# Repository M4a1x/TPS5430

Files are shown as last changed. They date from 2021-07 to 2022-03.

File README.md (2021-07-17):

# TPS5430

This is a small DC-DC Buck converter board based on the TPS5430 from TI specifically intended to be ordered from [JLCPCB](jlcpcb.com/) with few "extended parts". This was a practice project for me, so please feel free to point out any [issues](https://github.com/M4a1x/TPS5430/issues).

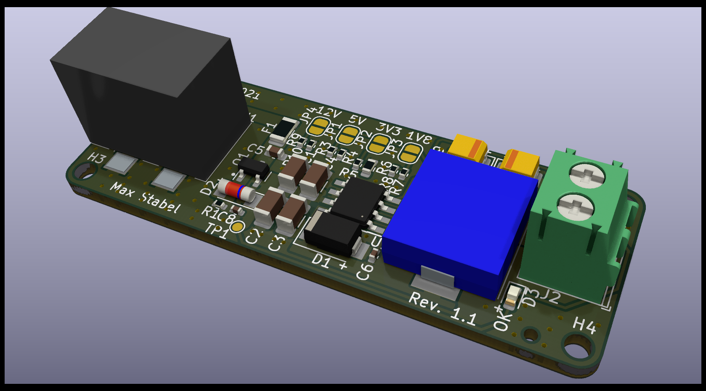
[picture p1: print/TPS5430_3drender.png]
Raytrace 3D rendered image of the TPS5430 board TPS5430


## Features

* V<sub>in</sub> = 5.5V..36V
* V<sub>in<sub>min</sub></sub> = 1.15 * V<sub>out</sub> (see Datasheet Section 8.2.1.2.8.1)
* V<sub>in<sub>max</sub></sub> = 8.33 * (V<sub>out</sub> + 0.5) (see Datasheet Section 8.2.1.2.8.1)
* V<sub>out</sub> = 1.8V/3.3V/5V/12V (choose via solder bridge)
* Reverse polarity protection with AO3401A p-MOSFET
* 3A (hold)/6A (trip) polyfuse input protection
* The board can be powered with a 2.1mm/5.5mm "standard" Arduino compatible barrel jack connector.
* Status LED

## Schematic

The design was done in [KiCAD 6 nightly (aka 5.99)](https://www.kicad.org/) and follows the [TPS5430 datasheet (Section 8.2.1)](https://www.ti.com/lit/ds/symlink/tps5430.pdf) reasonably close in the schmatic as well as the layout (Section 10.2).

Deviations are:

* 2x 100uF tantalum capacitors instead of 1x 220uF, since those are basic parts at JLCPCB
* As suggested a 10uF output bypass capacitor is added
* 4x 10uF input capacitors instead of only 1x
* Multiple output voltage options through increased Inductor (47uH instead of 15uH) and solder jumpers. All outputs should work with the full 3A

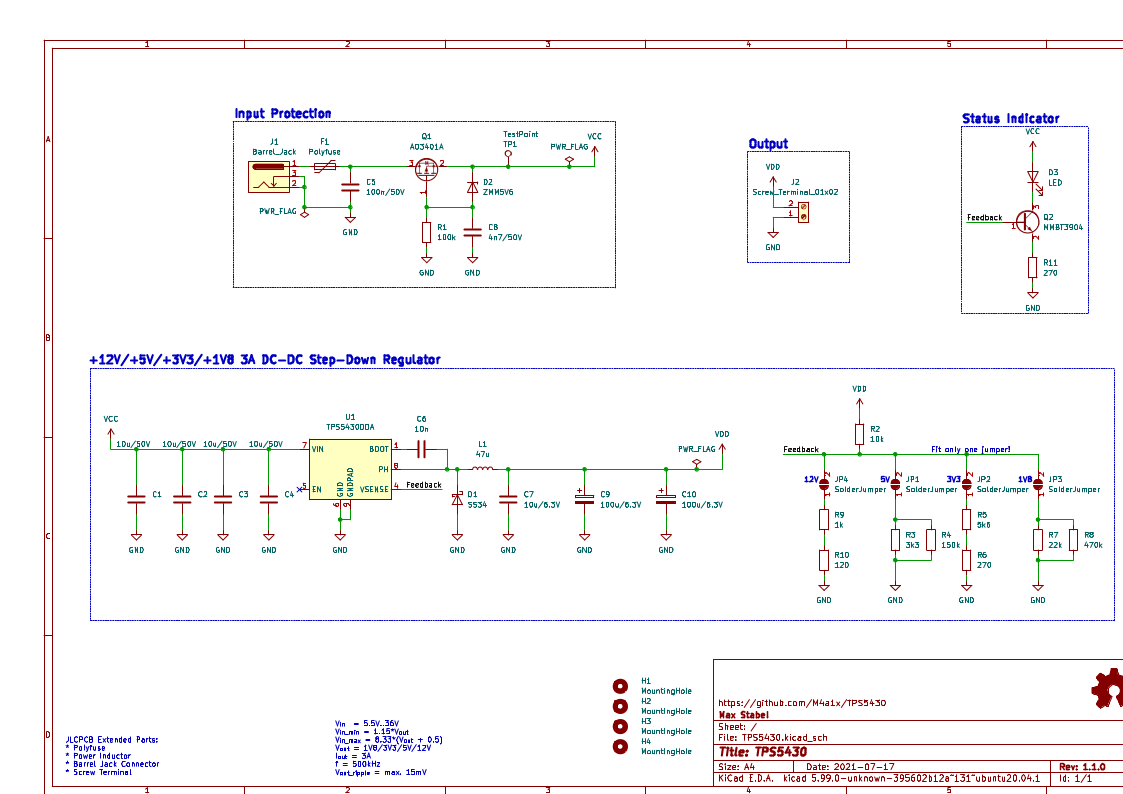
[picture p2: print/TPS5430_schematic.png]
Full schematic of the TPS5430 board Schematic


## License

Licensed under CERN-OHL-S v2 or any later version. See `LICENSE` for more information.

## Contact

Max Stabel - [https://max.stabel.family/](https://max.stabel.family)

Project Link: [https://github.com/M4a1x/TPS5430](https://github.com/M4a1x/TPS5430)

## Acknowledgements

* [Philip Salamony](https://philsal.co.uk/) and his [BananaSchplit Project](https://github.com/pms67/BananaSchplit) and [Video](https://www.youtube.com/watch?v=qXWYXxDokv4)
* [ugurozkan52/TPS5430_Power_Module](https://github.com/ugurozkan52/TPS5430_Power_Module) which inspired me to add the output voltage jumpers

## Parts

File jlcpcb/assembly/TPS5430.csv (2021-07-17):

Comment | Designator | Footprint | LCSC
10u/50V | C1,C2,C3,C4 | Capacitor_SMD:C_1206_3216Metric | C13585
100n/50V | C5 | Capacitor_SMD:C_0603_1608Metric | C14663
10n | C6 | Capacitor_SMD:C_0402_1005Metric | C15195
10u/6.3V | C7 | Capacitor_SMD:C_0402_1005Metric | C15525
4n7/50V | C8 | Capacitor_SMD:C_0402_1005Metric | C1538
100u/6.3V | C9,C10 | Capacitor_Tantalum_SMD:CP_EIA-3528-21_Kemet-B | C16133
SS34 | D1 | Diode_SMD:D_SMA | C8678
ZMM5V6 | D2 | Diode_SMD:D_MiniMELF | C8062
LED | D3 | LED_SMD:LED_0603_1608Metric | C72043
Polyfuse | F1 | Fuse:Fuse_1206_3216Metric | C207041
MountingHole | H1,H2,H3,H4 | MountingHole:MountingHole_2.2mm_M2_ISO7380
Barrel_Jack | J1 | tps5430:DC-005-5A-2.0-SMT | C319134
Screw_Terminal_01x02 | J2 | TerminalBlock_Phoenix:TerminalBlock_Phoenix_PT-1,5-2-3.5-H_1x02_P3.50mm_Horizontal | C784940
SolderJumper | JP1,JP2,JP3,JP4 | Jumper:SolderJumper-2_P1.3mm_Open_RoundedPad1.0x1.5mm
47u | L1 | tps5430:L_Sunlord_MWSA1004S_10x11.5x4mm | C408491
Logo_Open_Hardware_Small | LOGO1 | Symbol:OSHW-Logo_11.4x12mm_Copper
AO3401A | Q1 | Package_TO_SOT_SMD:SOT-23 | C15127
MMBT3904 | Q2 | Package_TO_SOT_SMD:SOT-23 | C20526
100k | R1 | Resistor_SMD:R_0402_1005Metric | C25741
120 | R10 | Resistor_SMD:R_0402_1005Metric | C25079
10k | R2 | Resistor_SMD:R_0402_1005Metric | C25744
3k3 | R3 | Resistor_SMD:R_0402_1005Metric | C25890
150k | R4 | Resistor_SMD:R_0402_1005Metric | C25755
5k6 | R5 | Resistor_SMD:R_0402_1005Metric | C25908
270 | R6,R11 | Resistor_SMD:R_0603_1608Metric | C22966
22k | R7 | Resistor_SMD:R_0402_1005Metric | C25768
470k | R8 | Resistor_SMD:R_0402_1005Metric | C25790
1k | R9 | Resistor_SMD:R_0402_1005Metric | C11702
TestPoint | TP1 | TestPoint:TestPoint_Pad_D1.0mm
TPS5430DDA | U1 | Package_SO:TI_SO-PowerPAD-8_ThermalVias | C9864

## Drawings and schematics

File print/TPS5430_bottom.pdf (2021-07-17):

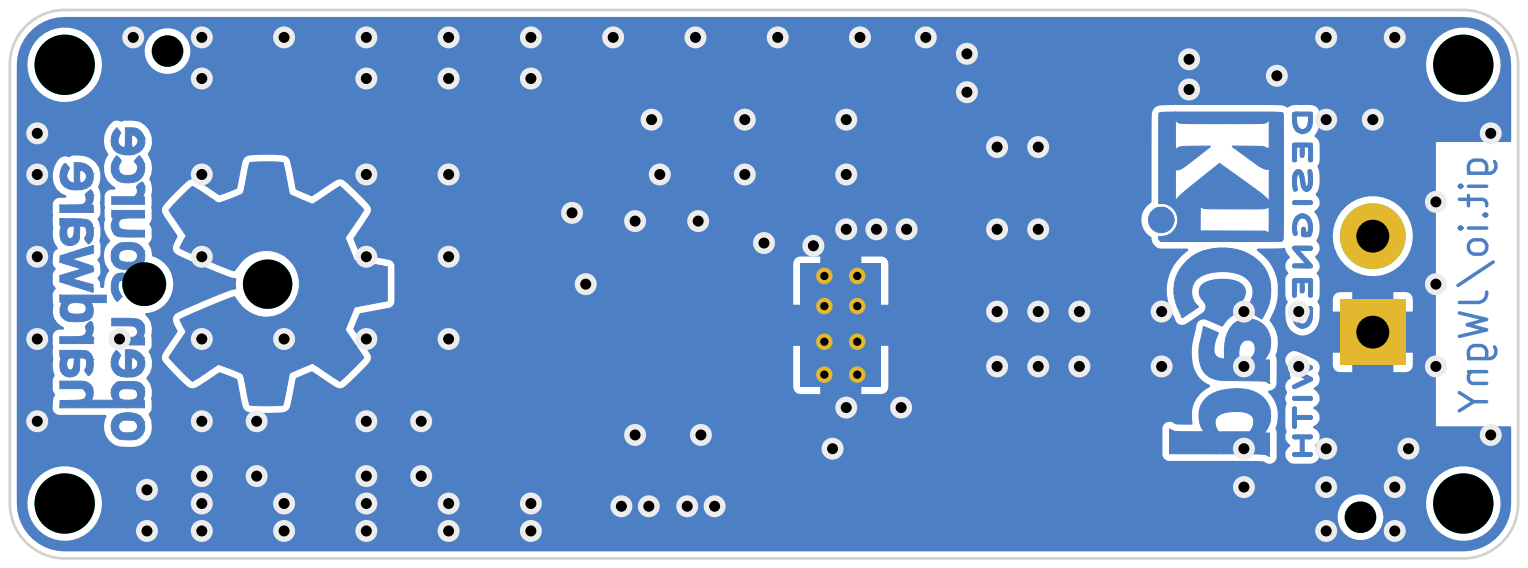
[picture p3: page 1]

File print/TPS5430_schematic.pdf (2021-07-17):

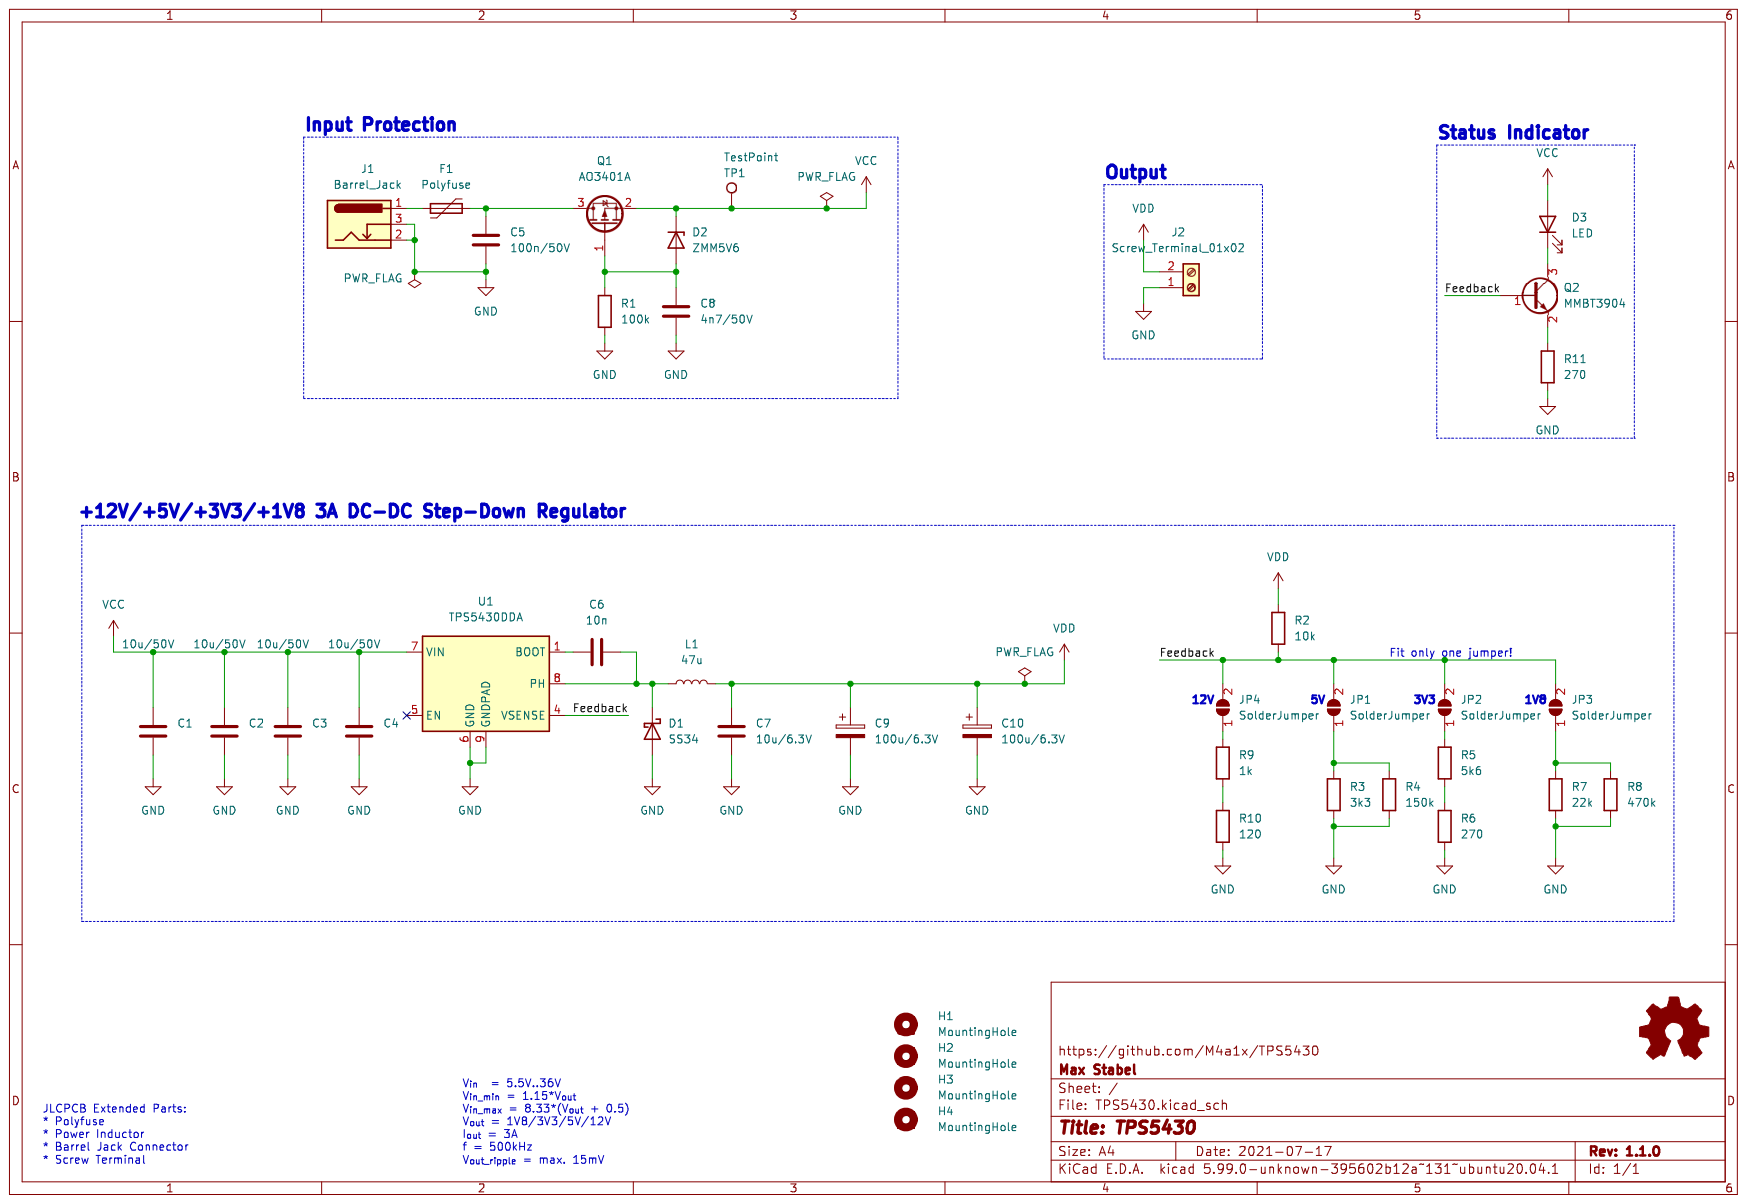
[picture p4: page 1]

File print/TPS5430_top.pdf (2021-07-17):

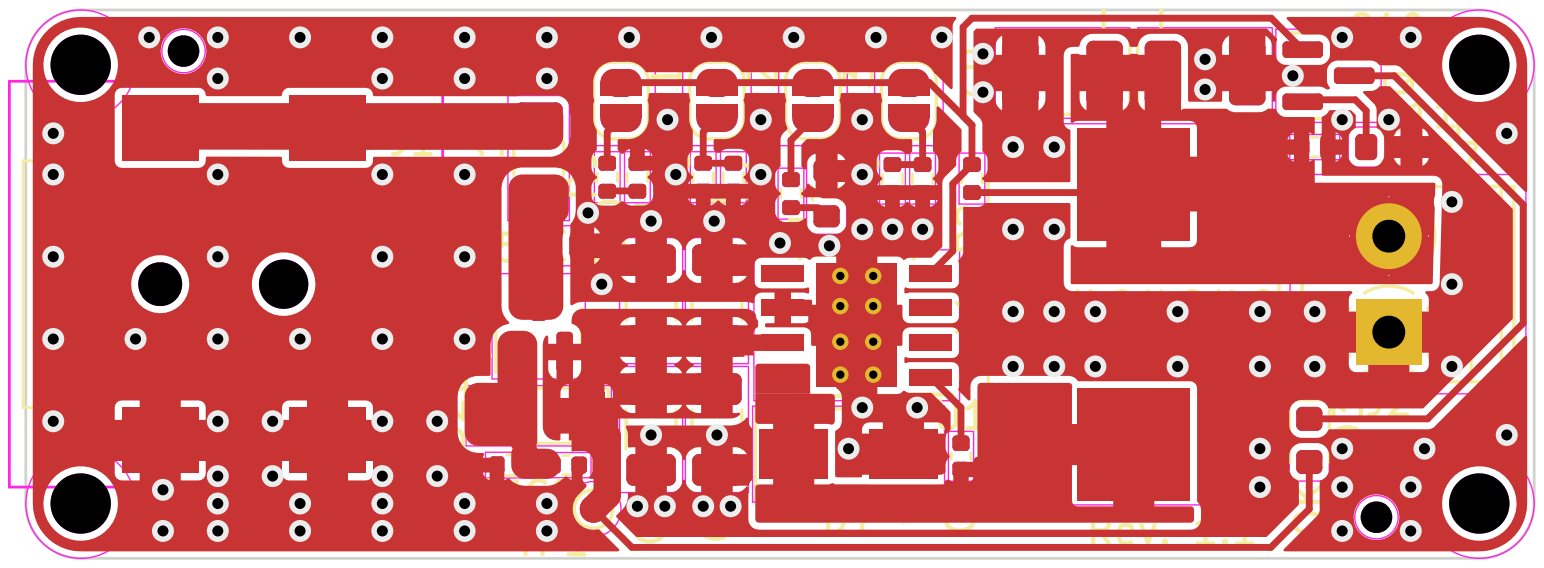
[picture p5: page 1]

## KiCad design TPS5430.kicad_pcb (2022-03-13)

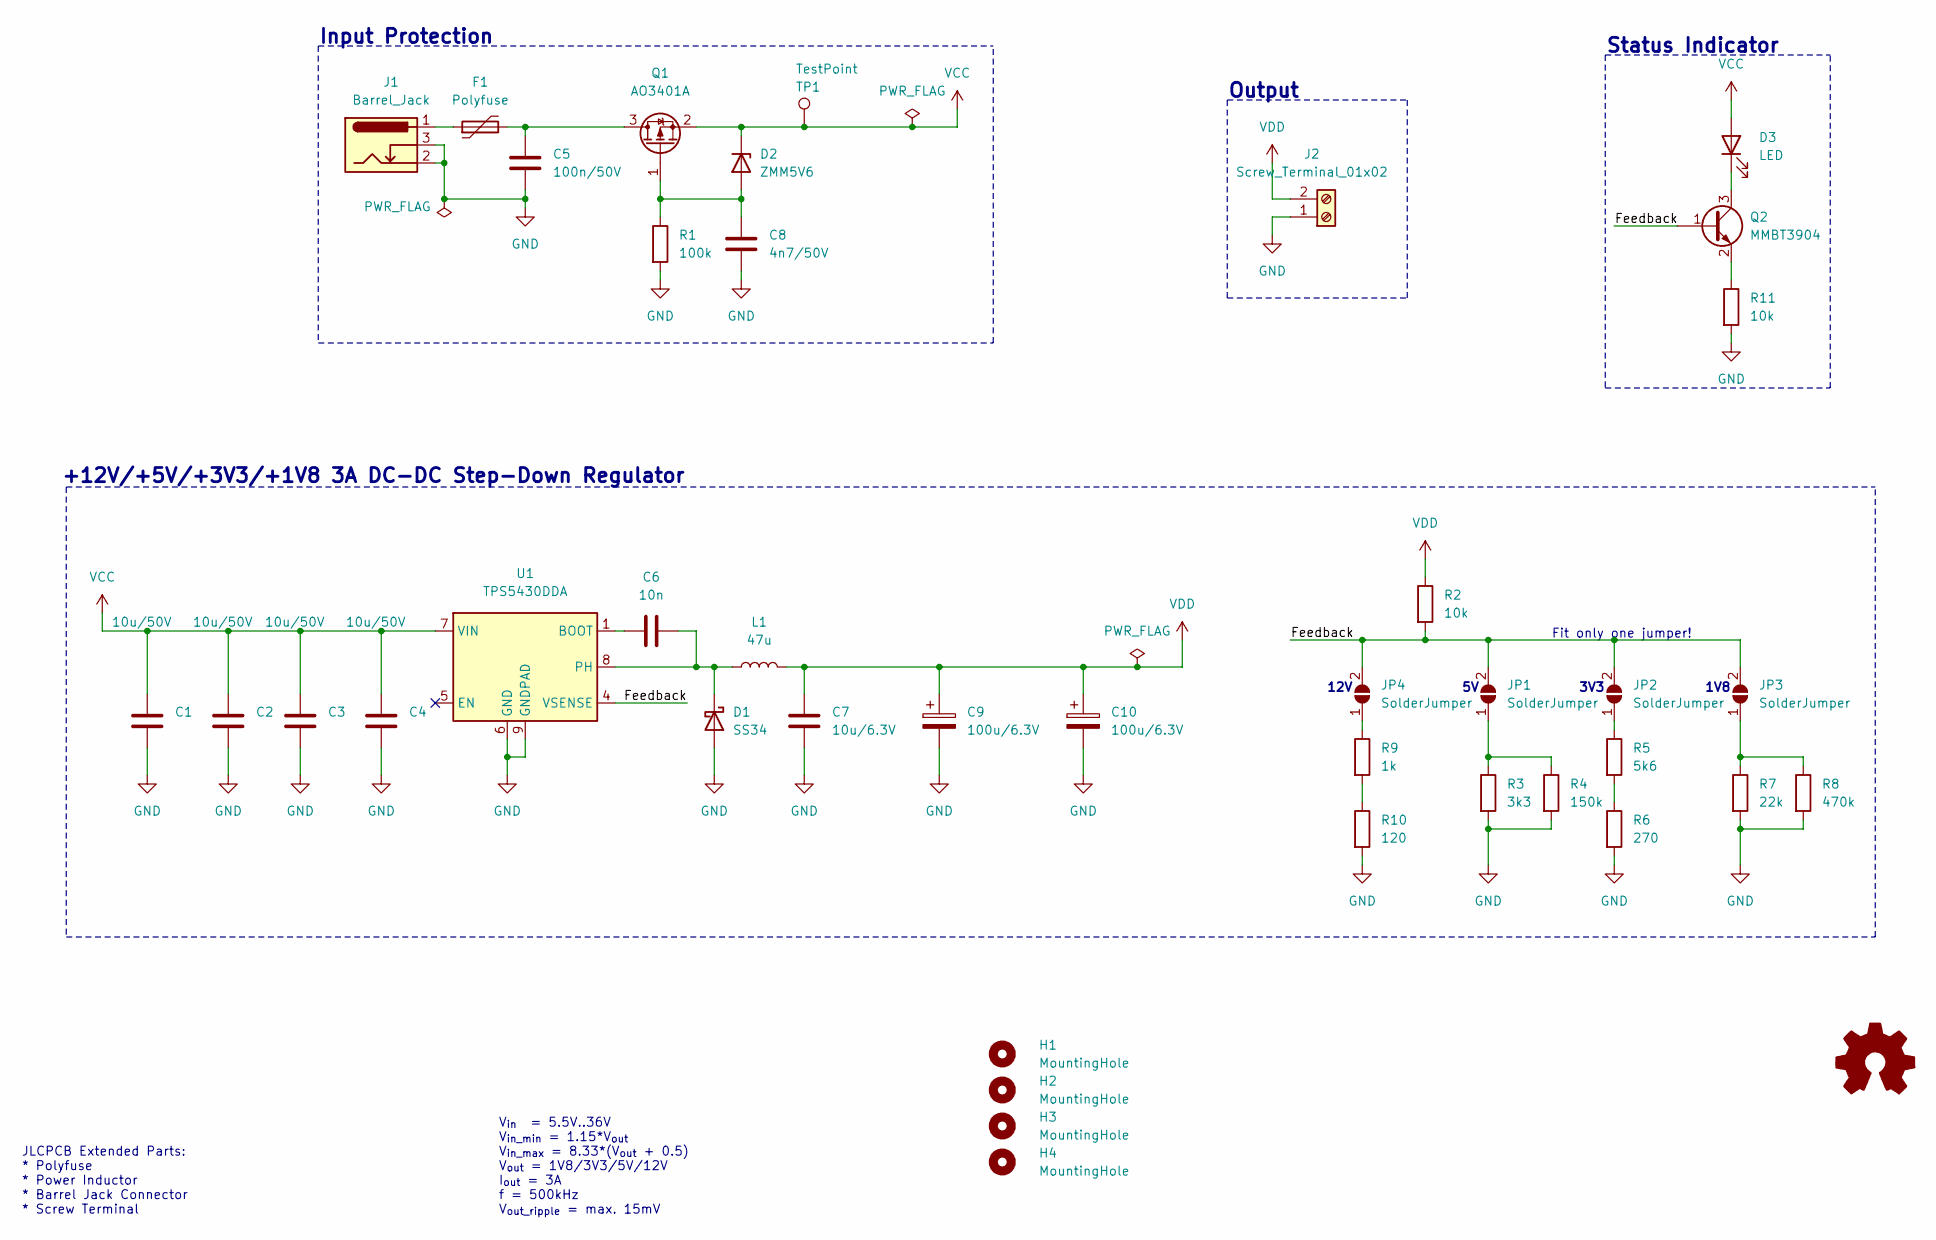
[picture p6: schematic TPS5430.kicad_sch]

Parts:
C1, C2, C3, C4: 10u/50V; C_1206_3216Metric; MPN CL31A106KBHNNNE; LCSC C13585
C5: 100n/50V; C_0603_1608Metric; MPN CC0603KRX7R9BB104; LCSC C14663
C6: 10n; C_0402_1005Metric; MPN CL05B103KB5NNNC; LCSC C15195
C7: 10u/6.3V; C_0402_1005Metric; MPN CL05A106MQ5NUNC; LCSC C15525
C8: 4n7/50V; C_0402_1005Metric; MPN 0402B472K500NT; LCSC C1538
C9, C10: 100u/6.3V; CP_EIA-3528-21_Kemet-B; MPN TAJB107K006RNJ; LCSC C16133
D1: SS34; D_SMA; MPN SS34; LCSC C8678
D2: ZMM5V6; D_MiniMELF; MPN ZMM5V6; LCSC C8062
D3: LED; LED_0603_1608Metric; MPN 19-217/GHC-YR1S2/3T; LCSC C72043
F1: Polyfuse; Fuse_1206_3216Metric; MPN 1206L300SLTHYR; LCSC C207041
H1, H2, H3, H4: MountingHole; MountingHole_2.2mm_M2_ISO7380
J1: Barrel_Jack; DC-005-5A-2.0-SMT; MPN DC-005-5A-2.0-SMT; LCSC C319134
J2: Screw_Terminal_01x02; TerminalBlock_Phoenix_PT-1,5-2-3.5-H_1x02_P3.50mm_Horizontal; MPN XY302V-3.5-2P; LCSC C784940
JP1, JP2, JP3, JP4: SolderJumper; SolderJumper-2_P1.3mm_Open_RoundedPad1.0x1.5mm
L1: 47u; L_Sunlord_MWSA1004S_10x11.5x4mm; MPN MWSA1004S-470MT; LCSC C408491
LOGO1: Logo_Open_Hardware_Small; OSHW-Logo_11.4x12mm_Copper
Q1: AO3401A; SOT-23; MPN AO3401A; LCSC C15127
Q2: MMBT3904; SOT-23; MPN MMBT3904; LCSC C20526
R1: 100k; R_0402_1005Metric; MPN 0402WGF1003TCE; LCSC C25741
R2: 10k; R_0402_1005Metric; MPN 0402WGF1002TCE; LCSC C25744
R3: 3k3; R_0402_1005Metric; MPN 0402WGF3301TCE; LCSC C25890
R4: 150k; R_0402_1005Metric; MPN 0402WGF1503TCE; LCSC C25755
R5: 5k6; R_0402_1005Metric; MPN 0402WGF5601TCE; LCSC C25908
R6: 270; R_0603_1608Metric; MPN 0603WAF2700T5E; LCSC C22966
R7: 22k; R_0402_1005Metric; MPN 0402WGF2202TCE; LCSC C25768
R8: 470k; R_0402_1005Metric; MPN 0402WGF4703TCE; LCSC C25790
R9: 1k; R_0402_1005Metric; MPN 0402WGF1001TCE; LCSC C11702
R10: 120; R_0402_1005Metric; MPN 0402WGF1200TCE; LCSC C25079
R11: 10k; R_0603_1608Metric; MPN 0603WAF1002T5E; LCSC C25804
TP1: TestPoint; TestPoint_Pad_D1.0mm
U1: TPS5430DDA; TI_SO-PowerPAD-8_ThermalVias; MPN TPS5430DDAR; JLC LSOP-8_EP_3.9x4.9x1.27P

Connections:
/Feedback: JP1.2 (B), JP2.2 (B), JP3.2 (B), JP4.2 (B), Q2.1 (B), R2.2, U1.4 (VSENSE)
GND: C1.2, C2.2, C3.2, C4.2, C5.2, C7.2, C8.2, C9.2, C10.2, D1.2 (A), J1.2, J1.3, J2.1, R1.2, R3.2, R4.2, R6.2, R7.2, R8.2, R10.2, R11.2, U1.6 (GND), U1.9 (GNDPAD)
unnamed: C5.1, F1.2, Q1.3 (D)
unnamed: C6.1, U1.1 (BOOT)
unnamed: C6.2, D1.1 (K), L1.1, U1.8 (PH)
unnamed: C8.1, D2.2 (A), Q1.1 (G), R1.1
unnamed: D3.1 (K), Q2.3 (C)
unnamed: F1.1, J1.1
unnamed: JP1.1 (A), R3.1, R4.1
unnamed: JP2.1 (A), R5.1
unnamed: JP3.1 (A), R7.1, R8.1
unnamed: JP4.1 (A), R9.1
unnamed: Q2.2 (E), R11.1
unnamed: R5.2, R6.1
unnamed: R9.2, R10.1
VCC: C1.1, C2.1, C3.1, C4.1, D2.1 (K), D3.2 (A), Q1.2 (S), TP1.1, U1.7 (VIN)
VDD: C7.1, C9.1, C10.1, J2.2, L1.2, R2.1

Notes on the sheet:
Fit only one jumper!
1V8
Status Indicator
JLCPCB Extended Parts: * Polyfuse * Power Inductor * Barrel Jack Connector * Screw Terminal
3V3
Output
12V
Input Protection
+12V/+5V/+3V3/+1V8 3A DC-DC Step-Down Regulator
V_{in} = 5.5V..36V V_{in_min} = 1.15*V_{out} V_{in_max} = 8.33*(V_{out} + 0.5) V_{out} = 1V8/3V3/5V/12V I_{out} = 3A f = 500kHz V_{out_ripple} = max. 15mV

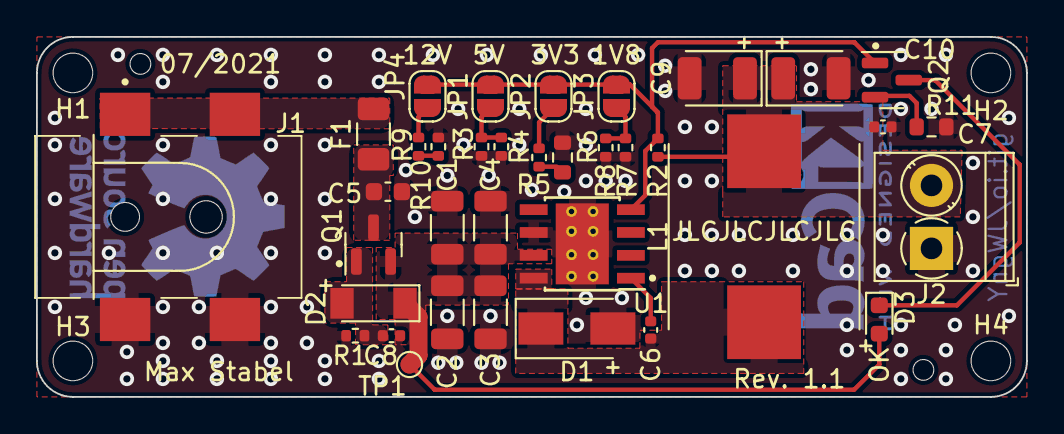
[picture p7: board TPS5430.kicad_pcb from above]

Board: 2 copper layers, 55.0 x 20.0 mm, 41 parts (1 on the bottom side), 17 nets.

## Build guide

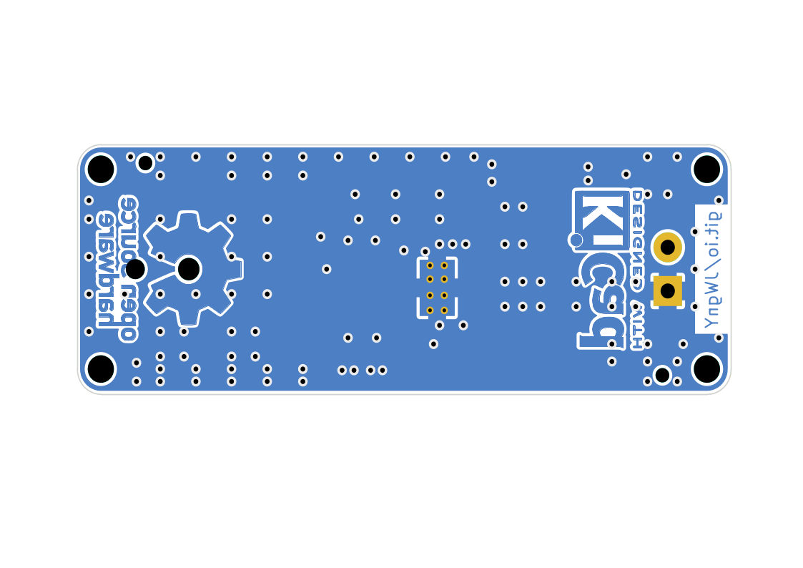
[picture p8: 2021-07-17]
print/TPS5430_bottom.png

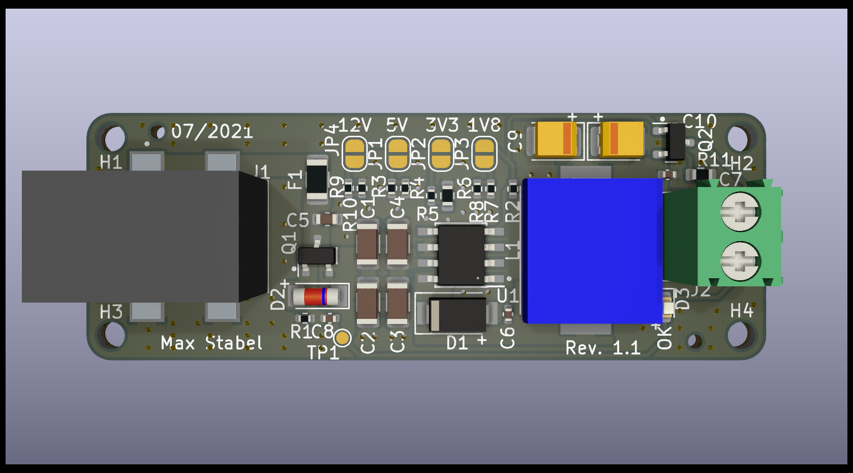
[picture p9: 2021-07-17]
print/TPS5430_3drender_top.png

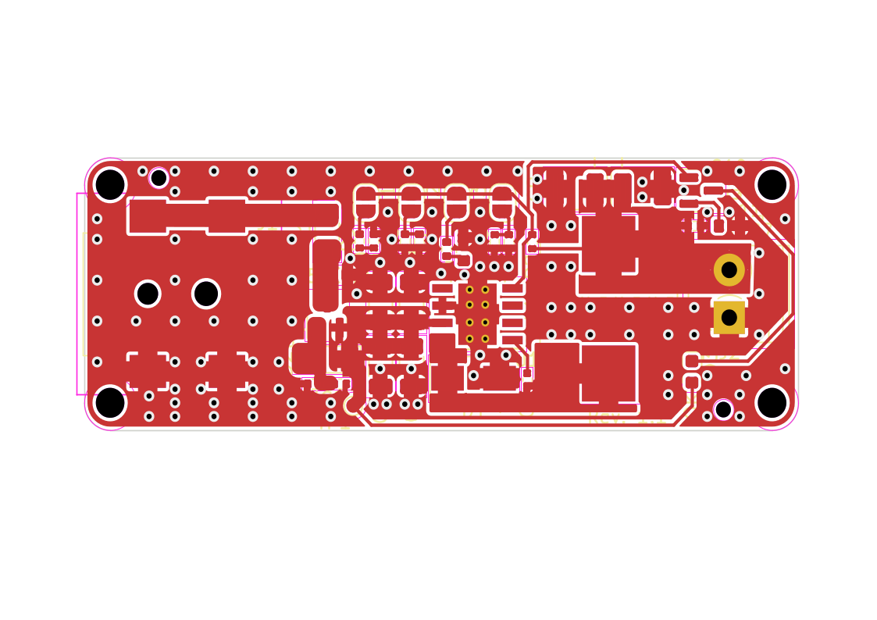
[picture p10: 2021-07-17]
print/TPS5430_top.png

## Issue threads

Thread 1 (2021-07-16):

Review Reverse Polarity Protection

M4a1x, 2021-07-16:
A user on reddit (/u/mechbuy) asked what the purpose of the 100nF capacitor is on the reverse polarity protection is. I saw that in the CM4IO Module and used it as well, assuming it's either slow start or inrush control. After simulating it (see docs folder), I figured that it should probably be a 4.7nF-10nF Capacitor between gate and ground instead, to switch off the mosfet fast enough if there's a sudden voltage change at the input. As seen here: https://electronics.stackexchange.com/questions/461898/reverse-polarity-protection-p-channel-mosfet

Slow start is not needed because of the slow start control of the TPS5430 and the capacitors in front of it.

The value of the resistor can probably be increased to ~100k as seen a lot on the internet to reduce power consumption (again, the old one was inspired by the CM4IO board).

M4a1x, 2021-07-17:
Changed the Cap to go between gate and ground, the capacity to 4.7nF and the voltage rating to 50V in fd8af0d99b00d8b7e58aa25f09d8118a33a80ed2

Closed 2021-07-17.

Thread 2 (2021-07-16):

Change Reverse Polarity MOSFET

M4a1x, 2021-07-16:
Ordering at JLCPCB I noticed that there's a minimum quantity of 15 for the AO3401A. Incidentially I found an even "better" pMOSFET that's also a basic part: [APM4953KC-TRG](https://datasheet.lcsc.com/lcsc/1810201610_Anpec-Elec-APM4953KC-TRG_C20897.pdf), that also switches as 4.5V (80mOhm R_gs) and has a even higher V_gs of +-25V

I believe simple switching them out would be sufficient to save a bit of money :)

M4a1x, 2021-07-17:
The pMOS I found is indeed cheaper, but it's also a double pMOSFET with a significantly larger package. I don't think the cost advantage of a few cents per board is worth fiddling with the arrangement of the parts. Since the reverse polarity protection needs to use a resistor+zener combination anyway, there's no other advantage as far as I can see.

Thus closing.

Closed 2021-07-17.

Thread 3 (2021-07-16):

Add V_out status LED

M4a1x, 2021-07-16:
It would be nice to have a status LED at the output with a low current (thinking of ~2mA) that shows if the output is working. Since the regulator maintains a constant 1.221V in stead-state operation, this could be used to control the current through an LED as described here:
https://electronics.stackexchange.com/questions/87713/driving-a-led-from-a-wide-ranging-input-voltage
and
https://electronics.stackexchange.com/questions/293062/how-to-achieve-constant-current-for-led-when-voltage-is-variable-in-mcu

M4a1x, 2021-07-17:
After some consideration, this could work down to even 1.8V output if I use the input rail to power the LED and control the base of the transistor with the sense/feedback pin

M4a1x, 2021-07-17:
After simulating my idea I implemented that in e024ccc1fa430ccfe0d76d37ba564d37b0c67b0e
I hope this works :)
Closing. Making a new issue if it's not working.

Closed 2021-07-17.

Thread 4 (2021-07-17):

Add Testpads/points

M4a1x, 2021-07-17:
Since this is the first run, it would be nice to be able to look at all/most of the intermediate voltages to see if something is off or oscillating at an unwanted frequency. Thus a few test points would be nice, maybe even test pins

M4a1x, 2021-07-17:
Since the V_out can very easily be measured at the output screw terminal and the feedback voltage at on of the solder jumper pads, I only added one for the Vcc input right before the regulator, to check the voltage after reverse polarity protection + fuse.

Closing for now, since I don't see any other points I'd want to measure.

Closed 2021-07-17.

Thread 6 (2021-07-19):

Rotation of screw terminal

M4a1x, 2021-07-19:
JLCPCB (Susie) reached out, because of the rotation of the screw terminal. There might be a rotation issue in the position file that I should verify.

M4a1x, 2022-03-12:
After some thought, maybe get rid of all of the through hole components (i.e. this one), so the PCB can lay flat.

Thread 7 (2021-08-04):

Move solder jumpers to backside

M4a1x, 2021-08-04:
Since it doesn't require any parts, I think moving just the solder jumpers (and any test points) to the back side would be a good idea to save some space and make the board even smaller.

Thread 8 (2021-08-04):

Add bottom silkscreen

M4a1x, 2021-08-04:
It looks like a bottom silkscreen is doable, which I could've thought of before.. It might help to add some additional comments/descriptions on the bottom, e.g. for connectors or the OSS logo/link

M4a1x, 2022-03-12:
Looking at the finished PCB I quite like the logos & links in the copper vs another silkscreen. So I'd not do it for now unless someone has a great idea :)

Closed 2022-03-12.

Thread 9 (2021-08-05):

Change status LED

M4a1x, 2021-08-05:
Current status LED has a forward drop voltage of ~2.8V, thus it won't turn on with V_out of 1.8V. A lower voltage drop would make it possible to work with lower input voltages.

Verify that the transistor circuit still works

Maybe remove the transistor circuit altogether and just use a resistor that results in an acceptable forward current through the diode for all output voltages, i.e. max. ~25mA, min ~1mA, for V_out of 1.8V to 12V

M4a1x, 2022-03-12:
Since I use the input voltage, which is a minimum of 5.5V the LED can light up for any input voltage.
But it only lights up if the output is on as well (as the transistor base is connected to the feedback).

Closed 2022-03-12.

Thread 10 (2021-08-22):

Capacitor voltage rating is not considered for 12V output

pmnxis, 2021-08-22:
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
```
TAJB107K006RNJ
C16133
1.7Ω 100kHz 6.3V -55℃~+125℃ 100uF ±10% CASE-B_3528 Tantalum Capacitors ROHS
```
Your schematic considered to use 12V for output. But output capacitor does not consider to use it. Because It's 6.3V rating.
Also can you check maximum ESR for capcitor?

M4a1x, 2021-09-06:
Hi,
thanks for taking interest in my little project, I really appreciate you opening an issue.

You're completely right, the capacitors are not suited for the 12V output option. It was added a bit hastily after the fact and I haven't verified all specs. Obviously that wasn't the greatest idea and you probably shouldn't use the 12V output.

Regarding the ESR: I remember that the ESR was more on the low side, as it needs to be high enough to prevent ringing on the output. There's a section in the datasheet (8.2.3) on using ceramic capacitors with a resistor network for the output filter. That also means using a electrolytic cap instead would be perfectly fine.

I currently don't have much time at hand, but I'll try to redo the calculations for the output capacitors including ESR next week. I don't know how I'll change the current ones though, as the idea was to use only basic parts from JLCPCB and the ones currently used have the highest capacitance of those AFAIK.

I'm open to any suggestions.

Cheers,
Max

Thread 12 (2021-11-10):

Replace through-hole screw terminal with an SMD variant

M4a1x, 2021-11-10:
Brings down cost (as it doesn't need to be hand soldered)

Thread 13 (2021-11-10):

Check if a smaller inductance would bring the price down

M4a1x, 2021-11-10:
If so, redo the calculations for all voltages

M4a1x, 2022-03-13:
Since all basic parts of JLCPCB currently don't support more than 500mA an extended part has to be used. The price difference between the suitable inductances is in the low single-digit cents. Thus I don't consider this an issue.

Closed 2022-03-13.

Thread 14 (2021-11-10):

Move connectors to other side

M4a1x, 2021-11-10:
As the connectors are often soldered by hand at JLCPCB (check!), there'd probably be no difference in pricing if they were to be placed on the back side to make the PCB even smaller.

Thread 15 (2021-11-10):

Add input ok LED

M4a1x, 2021-11-10:
Add an LED for the input with a resistor in series, rated for the highest voltage. It will just get dimmer for lower voltages. This should work as the minimum input voltage is 5.5V

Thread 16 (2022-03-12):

Fix 5V output level

M4a1x, 2022-03-12:
After some testing it looks like the output level of the 5V rail is quite a bit too high (almost 7V sometimes). Recheck resistors in the feedback loop!

M4a1x, 2022-03-12:
Well, turns out I made a mistake while soldering the jumpers. The 5V output is completely fine

Closed 2022-03-12.

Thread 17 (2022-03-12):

Add USB-C?

M4a1x, 2022-03-12:
Usually, I have either my Laptop/Desktop around or one of those cheap barrel jack power supplies. To make this board even more versatile I could add a USB-C plug with a USB-PD chip that negotiates a voltage as high as possible. Unfortunately, this would probably mean I'd have to use an extended part.

M4a1x, 2022-03-12:
Maybe do this on a separate board with a TPS54331, as that goes down to 3.5V input voltage and seems to be the "newer" version: https://e2e.ti.com/support/power-management-group/power-management/f/power-management-forum/60588/help---tps5430-tps54331

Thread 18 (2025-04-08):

Output voltage of 1.8V not possible if input over 12V

DeepCoreSystem, 2025-04-08:
As per the Texas Instruments tool WeBench, an input voltage above approx. 12V violates the min on time/max duty cycle for an output voltage of 1.8V.

See this screenshot:

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

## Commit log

2021-07-15 Add page description
    [TPS5430.kicad_pcb, TPS5430.kicad_sch]
2021-07-15 Gerber re-export
    [TPS5430-B_Cu.gbl, TPS5430-B_Mask.gbs, TPS5430-B_Paste.gbp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]
2021-07-15 Add library with used extra parts
    [TPS5430.kicad_pcb, TPS5430.kicad_sch]
2021-07-15 Add renders/printouts
2021-07-15 Update .gitignore to add JLCPCB order information
    [TPS5430.csv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]
2021-07-16 Add License notice in files and on the PCB
    [TPS5430-B_Cu.gbl, TPS5430-B_Mask.gbs, TPS5430-B_Paste.gbp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]
2021-07-17 Add TP & 12V SolderJumper
    [TPS5430.kicad_pcb, TPS5430.kicad_sch]
2021-07-17 Add status led & reverse polarity simulations
2021-07-17 Fix led_drive simulation
2021-07-17 Add Status LED
    [TPS5430.kicad_pcb, TPS5430.kicad_sch]
2021-07-17 Add status LED & fix reverse polarity protection
    [TPS5430-B_Cu.gbl, TPS5430-B_Mask.gbs, TPS5430-B_Paste.gbp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]
2022-03-12 Dim status LED and update to KiCAD 6
    [TPS5430.kicad_pcb, TPS5430.kicad_sch]
2022-03-13 LTSpice: Change LED resistor to 10k as well
2022-03-13 Bump version to 1.1.1 for dimmed LED
    [TPS5430.kicad_pcb, TPS5430.kicad_sch]
